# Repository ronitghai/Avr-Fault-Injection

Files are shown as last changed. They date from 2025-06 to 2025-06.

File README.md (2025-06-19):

# Fault Injection on AES: Cryptographic Hardware Attack

### Overview
This project focused on exploiting vulnerabilities in AES encryption by inducing faults into embedded firmware running on an **ATMega328P** microcontroller and analyzing resulting data to recover the cipher key.

### Tech Stack
- **Firmware**: C/C++ on Arduino IDE
- **Microcontroller**: ATMega328P
- **Hardware Tools**: RP2040 (for fault injection), Zynq-7000 FPGA (initial testing)
- **Analysis**: Python (differential analysis)

### Key Features
- Implemented custom AES encryption in C on the victim MCU.
- Designed fault injection mechanism to corrupt encryption rounds.
- Collected and analyzed 1500 ciphertexts to extract partial cipher key.
- Used Python for statistical correlation and trace analysis.

### Development Summary
- Wrote both victim and attacker firmware in C.
- Designed fault injection testbed using GPIO-triggered timing delays.
- Switched to RP2040 for more precise glitching after testing with Zynq FPGA.
- Performed statistical analysis to reverse-engineer AES keys using Python scripts.

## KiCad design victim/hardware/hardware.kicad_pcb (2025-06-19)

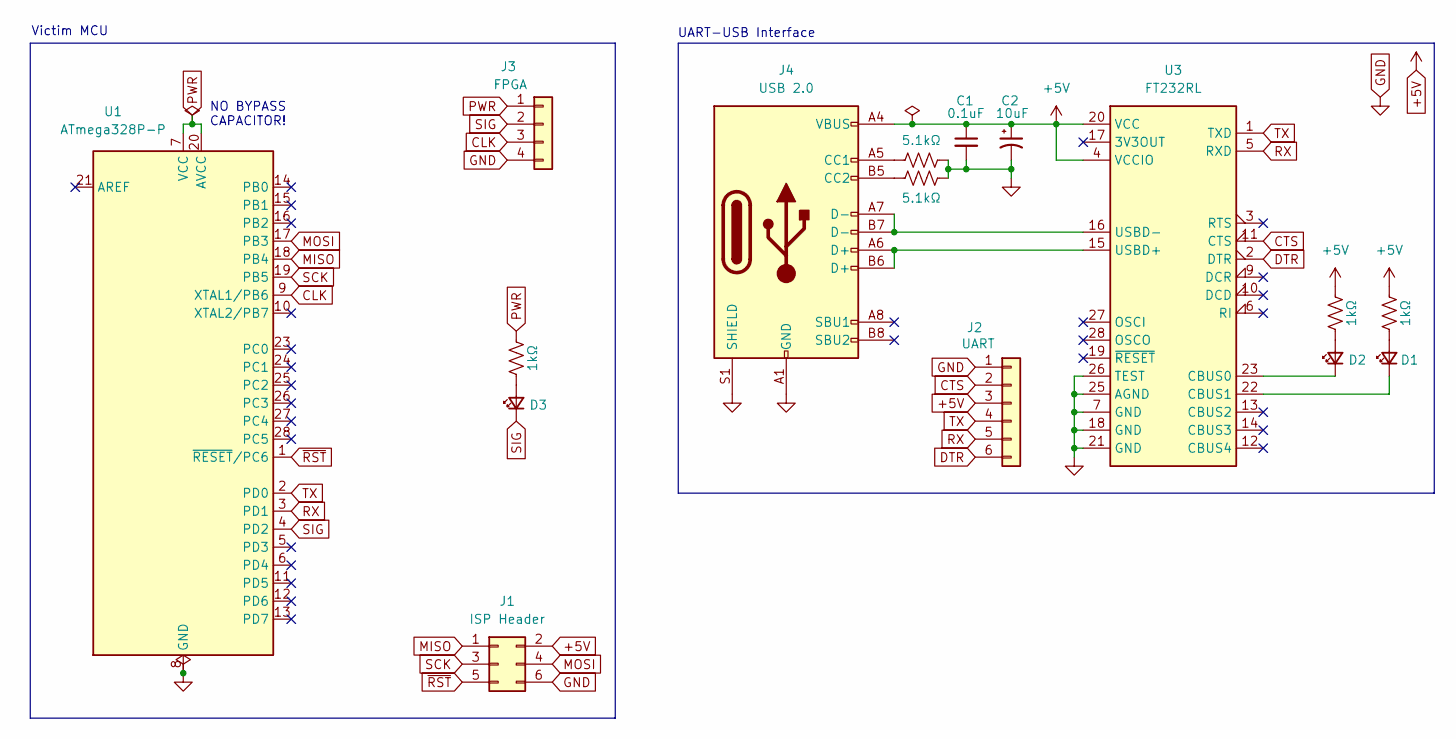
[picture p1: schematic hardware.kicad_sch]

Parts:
C1: 0.1uF; C_0805_2012Metric
C2: 10uF; C_0805_2012Metric
D1, D2, D3: LED_Small; LED_0805_2012Metric
J1: ISP Header; PinHeader_2x03_P2.54mm_Vertical
J2: UART; PinHeader_1x06_P2.54mm_Vertical
J3: FPGA; PinHeader_1x04_P2.54mm_Vertical
J4: USB 2.0; USB_C_Receptacle_G-Switch_GT-USB-7010ASV
R1, R2: 5.1kΩ; R_0805_2012Metric
R3, R4, R5: 1kΩ; R_0805_2012Metric
U1: ATmega328P-P; DIP-28_W7.62mm
U3: FT232RL; SSOP-28_5.3x10.2mm_P0.65mm

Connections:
+5V: C1.1, C2.1, J1.2, J2.3, J4.A4 (VBUS), J4.A9 (VBUS), J4.B4 (VBUS), J4.B9 (VBUS), R3.2, R4.2, U3.4 (VCCIO), U3.20 (VCC)
CLK: J3.3, U1.9 (XTAL1/PB6)
CTS: J2.2, U3.11 (CTS)
DTR: J2.6, U3.2 (DTR)
GND: C1.2, C2.2, J1.6, J2.1, J3.4, J4.A1 (GND), J4.A12 (GND), J4.B1 (GND), J4.B12 (GND), J4.S1 (SHIELD), R1.2, R2.2, U1.8 (GND), U1.22 (GND), U3.7 (GND), U3.18 (GND), U3.21 (GND), U3.25 (AGND), U3.26 (TEST)
MISO: J1.1, U1.18 (PB4)
MOSI: J1.4, U1.17 (PB3)
unnamed: D1.2 (A), R4.1
unnamed: D1.1 (K), U3.22 (CBUS1)
unnamed: D2.2 (A), R3.1
unnamed: D2.1 (K), U3.23 (CBUS0)
unnamed: D3.2 (A), R5.1
unnamed: J4.A5 (CC1), R1.1
unnamed: J4.B5 (CC2), R2.1
unnamed: J4.A6 (D+), J4.B6 (D+), U3.15 (USBD+)
unnamed: J4.A7 (D-), J4.B7 (D-), U3.16 (USBD-)
PWR: J3.1, R5.2, U1.7 (VCC), U1.20 (AVCC)
RX: J2.5, U1.3 (PD1), U3.5 (RXD)
SCK: J1.3, U1.19 (PB5)
SIG: D3.1 (K), J3.2, U1.4 (PD2)
TX: J2.4, U1.2 (PD0), U3.1 (TXD)
~RST: J1.5, U1.1 (~RESET/PC6)

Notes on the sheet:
NO BYPASS CAPACITOR!
UART-USB Interface
Victim MCU

Board: 2 copper layers, 16 parts (2 on the bottom side), 22 nets, no tracks yet.

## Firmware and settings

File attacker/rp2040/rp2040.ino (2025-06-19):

int mixSignal;

void signal_callback(uint gpio, uint32_t events){
    mixSignal = ++mixSignal % 4;
    //asm("nop");
    if(!mixSignal) {
      //Serial.println("attack");
      digitalWrite(24, LOW);
      asm("nop");
      asm("nop");
      asm("nop");
      asm("nop");
      asm("nop");
      asm("nop");
      asm("nop");
      asm("nop");
      asm("nop");
      asm("nop");
      asm("nop");
      asm("nop");
      asm("nop");
      asm("nop");
      asm("nop");
      asm("nop");
      asm("nop");
      asm("nop");
      asm("nop");
      asm("nop");
      asm("nop");
      asm("nop");
      asm("nop");
      asm("nop");
      asm("nop");
      asm("nop");
      asm("nop");
      asm("nop");
      asm("nop");
      asm("nop");
      asm("nop");
      asm("nop");
      digitalWrite(24, HIGH);
    
    //Serial.println("end attack");
  }
}

void setup() {
  Serial.ignoreFlowControl();
  Serial.begin(1800);
  Serial1.begin(1800);

  clock_gpio_init_int_frac(25, clk_usb, 48, 0);

  
  pinMode(11, INPUT);
  //gpio_set_irq_enabled_with_callback(11, GPIO_IRQ_EDGE_FALL, true, &signal_callback);

  pinMode(24, OUTPUT);
}

void loop() {
  mixSignal = -1;
  Serial1.flush();

  digitalWrite(24, HIGH);
  while(Serial1.available() < 16);

  String data = Serial1.readString();
  Serial.print(data);

  digitalWrite(24, LOW);
  delayMicroseconds(100000);
}

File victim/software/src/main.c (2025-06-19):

#include "aes-128.h"
#include "usart.h"

int main(int argc, char* argv[])
{
    const uint8_t cipherKey[] = { 0x00, 0x11, 0x22, 0x33, 0x44, 0x55, 0x66, 0x77, 0x88, 0x99, 0xAA, 0xBB, 0xCC, 0xDD, 0xEE, 0xFF };
    aes_key_t keyChain;
    init_aes_key(&keyChain, cipherKey);
    
    usart_init(1800);
    DDRD |= (1<<PD2);
    
    uint8_t trace[AES_BLOCKSIZE] = { 0 };
    encrypt(trace, &keyChain);

    usart_transmit_hex(trace, AES_BLOCKSIZE);
    usart_transmit_char('\r');
    usart_transmit_char('\n');

    return 0;
}
